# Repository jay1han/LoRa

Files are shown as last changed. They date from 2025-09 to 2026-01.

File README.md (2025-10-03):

# LoRa

This umbrella project contains several components utilizing LoRa for long-range, small-payload
communication for battery-driven applications.

## CellLoRa

This edge application collects atmospheric measurements (temperature, humidity) at hourly intervals
and sends a small data packet through LoRa. When not performing measurements, the module enters
a deep sleep state that consumes a few &mu;A of power. The module is powered by 3 AA batteries in series,
delivering between 3.5 and 5.0V, feeding a down-converter to 3.3V suitable for the electronics.
At each measurement time, the output voltage of the batteries is also measured,
so that a user can anticipate a low battery condition.

The CPU is a ESP32-C3 module, and atmospheric measurement is done with a AHT10.
Battery voltage is measured with a simple 10:1 resistor bridge connected to one of the internal
ADCs of the ESP32-C3. LoRa is provided by a Ra-02 module from AI-Thinker, which uses a SX1278
and is optimized for 433MHz. A relay and transistor is used to control power supply to it.

The system has been tested to run for several months on a set of 3 batteries.
The code has been optimized for reliability, doing 3 re-sends at maximum power, very low bandwidth
and high spread. Depending on the environment and the application, the reliability can be reduced
hence reducing power draw and extending battery life.

## LoRa2MQTT

This bridge application uses a ESP32-S2 with the same SX1280-based LoRa module.
It listens on the LoRa band for messages from edge applications, and takes appropriate action.
In the case of the CellLora, the incoming packet is parsed and the three measurements
(temperature, humidity, battery voltage) are bundled into a MQTT message.
Link to the MQTT broker goes through normal WiFi.

Additional edge devices can be added through the `Vector` array.
Some examples (`BalLoRa` and `Test`) have been provided for reference.

## Home Assistant

MQTT is used as the bridge for Home Assistant. A device named "CellLora" is self-registered
using the three configuration messages `temp.config`, `humi.config`, `batt.config`.
Use the `config.sh` script to run the self-registration, after the MQTT integration
has been enabled on Home Assistant.

After installing `mosquitto` and `mosquitto-client`,
create a password file:

```
mosquitto_passwd -c mosquitto.pwd <user>
```

then move the file `mosquitto.pwd` et `/etc/mosquitto`.

Add the following lines to `/etc/mosquitto/mosquitto.conf`:

```
per_listener_settings true
listener 1883
password_file /etc/mosquitto/mosquitto.pwd
```

then restart `mosquitto`.

Enable the MQTT integration of Home Assistant using the user/password defined above.

## About LoRa

LoRa, as its name implies, is optimized for long-range, low-bandwidth, broadcast communication
over unlicensed spectrum. Depending on geography, spectrum in the 433MHz, 915MHz, or 2.4GHz range
can be used. The lower frequencies typically allow better penetration while higher frequencies
allow higher bandwidth. In out *CellLoRa* application, the system has been tested to push data
from am enclosed cellar in the 2nd basement up to an appartement on the 5th floor of a concrete building.

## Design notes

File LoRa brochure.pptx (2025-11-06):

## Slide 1

Application LoRa pour mesure atmosphérique basse fréquence

Capteur atmosphérique

Relai MQTT

Fréquence de mesure : 1/heure
Distance à la base : plusieurs km (ou plusieurs étages)
Alimentation par 3 piles AA : endurance de plusieurs mois

Alimentation : 5V 200mA max.
Connexion Wi-Fi au broker MQTT
Intégration à Home Assistant

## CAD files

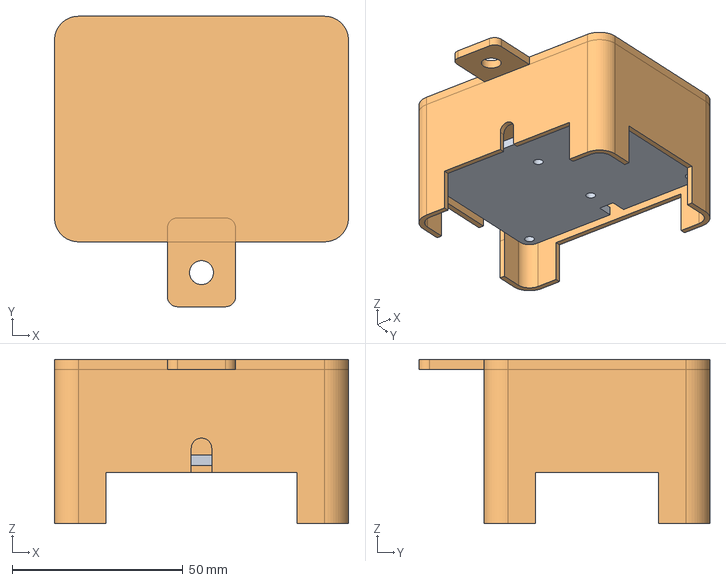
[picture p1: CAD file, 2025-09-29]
CellLora/CellLora.FCStd
86.0 x 85.0 x 48.0 mm
Base
Top

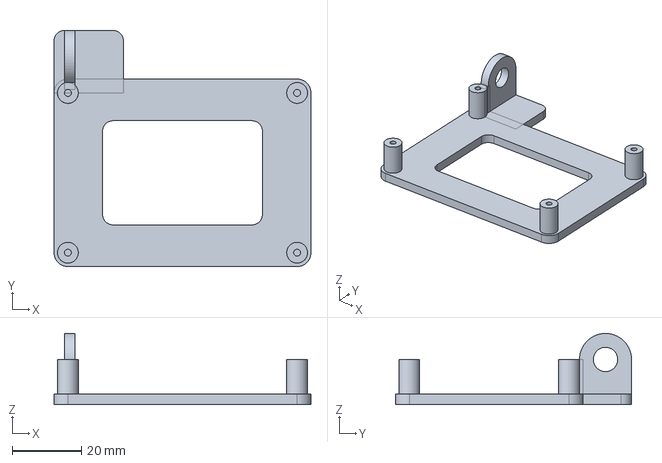
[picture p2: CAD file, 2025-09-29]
LoRa2MQTT/LoRa2MQTT.FCStd
74.0 x 68.0 x 20.5 mm

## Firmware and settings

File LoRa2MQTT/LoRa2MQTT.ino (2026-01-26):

#include <SPI.h>
#include <LoRa.h>
#include <WiFi.h>
#include <Wire.h>
#include <MQTT.h>
#include <Esp.h>

#define VERSION      "v200"

#define PIN_LED      15
#define PIN_BUTTON   0

#define LORA_RST     39
#define LORA_SCK     37
#define LORA_MISO    35
#define LORA_SS      33
#define LORA_MOSI    18
#define LORA_INT     16

#define I2C_SCL      3
#define I2C_SDA      5

#define SSID         "HORS SERVICE"
#define PASS         "babeface00"
WiFiClient wifiClient;

#define MQTT_SERVER  "192.168.0.86"
#define MQTT_TOPIC   "LoRa"
#define MQTT_CLIENT  "LoRa2MQTT"
#define MQTT_USER    "guest"
#define MQTT_PASSWD  "invitation"
MQTTClient mqttClient(1024);

// ----------------------------
// I2C for OLED display SSD1306

#define I2C_ADDR     0x3C

#define FONT_WIDTH    FONT_WIDTH_16
#define FONT_PITCH    (FONT_WIDTH + 1)
#define LCD_H_RES     128
#define LCD_V_RES     64
#define LCD_PAGES     (LCD_V_RES / 8)
#define LINE_WIDTH    (LCD_H_RES / FONT_PITCH / 2)
#include "fontdata.h"

const unsigned char ssd1306_init[] = {
    0xAE | 0x00,          // SET_DISP            off
    0xA0 | 0x01,          // SET_REG_REMAP       horizontal reverse start
    0xA8, LCD_V_RES - 1,  // SET_MUX_RATIO
    0xC0 | 0x08,          // SET_COM_OUT_DIR     horizontal reverse scan
    0xDA, 0x12,           // SET_COM_PIN_CFG     must be 0x02 if aspect ratio > 2:1, 0x12 otherwise
    0x20, 0x02,           // SET_MEM_ADDRESS     page mode
    0xD9, 0xF1,           // SET_PRECHARGE
    0xDB, 0x30,           // SET_VCOM_DESEL
    0x81, 0xFF,           // SET_CONTRAST
    0xA4,                 // SET_ENTIRE_ON
    0xA6 | 0x00,          // SET_NORM_INV (0x01 for inverse)
    0x8D, 0x14,           // SET_CHARGE_PUMP
    0xAE | 0x01,          // SET_DISP            on
};
unsigned char init_buffer[LCD_H_RES / 2 + 1];

void ssd1306_cmd(unsigned char cmd) {
    Wire.beginTransmission(I2C_ADDR);
    Wire.write(0x80);
    Wire.write(cmd);
    Wire.endTransmission();
}

void screenOn(bool on) {
    ssd1306_cmd(0x81);
    if (on) ssd1306_cmd(0xFF);
    else ssd1306_cmd(0x00);
}

void screenSaver(bool toggle) {
    static unsigned long lastOn = millis();
    static bool state = true;

    if (toggle) {
        if (!state) {
            screenOn(true);
            state = true;
            lastOn = millis() / 1000;
        } else {
            screenOn(false);
            state = false;
        }
    } else {
        if (state) {
            unsigned long now = millis() / 1000;
            if (now - lastOn > 60) {
                screenOn(false);
                state = false;
            }
        }
    }
}

void sendPagePos(int page, int pos, unsigned char *thisBuffer, int length) {
    ssd1306_cmd(0xB0 | page);
    ssd1306_cmd(0x00 | (pos & 0x0F));
    ssd1306_cmd(0x10 | (pos >> 4));
        
    Wire.beginTransmission(I2C_ADDR);
    Wire.write(0x40);
    Wire.write(thisBuffer, length);
    Wire.endTransmission();
}

void initDisplay() {
    memset(init_buffer, 0, sizeof(init_buffer));
    Wire.begin(I2C_SDA, I2C_SCL, 400000);
    Wire.beginTransmission(I2C_ADDR);
    if (Wire.endTransmission() == 0) {
        for (int i = 0; i < sizeof(ssd1306_init); i++) {
            ssd1306_cmd(ssd1306_init[i]);
        }

        for (int page = 0; page < LCD_PAGES; page ++) {
            sendPagePos(page, 0, init_buffer, sizeof(init_buffer));
            sendPagePos(page, LCD_H_RES / 2, init_buffer, sizeof(init_buffer));
        }
        Serial.println("I2C OLED initialized");
    } else {
        Serial.println("I2C OLED failed");
    }
}

byte nybble_low(byte original) {
    byte result = 0;
    for (int pos = 0; pos < 4; pos++) {
        if (original & (1 << pos)) result |= (3 << (pos * 2));
    }
    return result;
}

byte nybble_hi(byte original) {
    byte result = 0;
    for (int pos = 0; pos < 4; pos++) {
        if (original & (1 << (4 + pos))) result |= (3 << (pos * 2));
    }
    return result;
}

unsigned char lines[4][LCD_H_RES];

void writeBig(int line, char *text) {
    int target = 0;
    int i;

    for (i = 0; i < strlen(text) && i < LINE_WIDTH; i++) {
        int index = text[i];
        for (int col = 0; col < FONT_WIDTH_16; col++) {
            lines[0][target] = nybble_low(fontdata_top[index][col]);
            lines[1][target] = nybble_hi(fontdata_top[index][col]);
            lines[2][target] = nybble_low(fontdata_bot[index][col]);
            lines[3][target] = nybble_hi(fontdata_bot[index][col]);
            target++;
            lines[0][target] = nybble_low(fontdata_top[index][col]);
            lines[1][target] = nybble_hi(fontdata_top[index][col]);
            lines[2][target] = nybble_low(fontdata_bot[index][col]);
            lines[3][target] = nybble_hi(fontdata_bot[index][col]);
            target++;
        }
        lines[0][target] = lines[1][target] = lines[2][target] = lines[3][target] = 0x00;
        target++;
        lines[0][target] = lines[1][target] = lines[2][target] = lines[3][target] = 0x00;
        target++;
    }
    
    for (; target < LCD_H_RES; target++) {
        lines[0][target] = lines[1][target] = lines[2][target] = lines[3][target] = 0x00;
    }

    for (int sub = 0; sub < 4; sub++) {
        sendPagePos(line * 4 + sub, 0, lines[sub], target);
    }
}

// --------------------------------
// Global variables shared with ISR

#define MAX_PAYLOAD  16

#define ID_CELLAR   0xCE
#define ID_ERROR    0x55

struct {
    char message[16];
    char json[128];
    float battery;
    int rssi, snr;
} Rx;
byte payload[MAX_PAYLOAD];

#define HASS_TOPIC  "homeassistant/sensor/CellLora/state"
#define HASS_JSON   "{\"temperature\": %.1f, \"humidity\": %.0f, \"voltage\": %.1f}"

void sendMessage() {
    mqttClient.publish(MQTT_TOPIC, Rx.message);
    mqttClient.loop();
    if (!mqttClient.publish(HASS_TOPIC, Rx.json)) {
        Serial.println("Error publishing");
        sleep(1);
        ESP.restart();        
    }
    if (!mqttClient.loop()) {
        Serial.println("Loop error");
        sleep(1);
        ESP.restart();        
    }
}

char messageText[8];
char dataText[8];
void skipMessage(char *text) {
    while(LoRa.peek() >= 0) LoRa.read();
    if (text != NULL) {
        strcpy(messageText, text);
    }
}

bool isReceived = false;
void parseMessage(int packetSize) {
    int length = LoRa.available();
    if (length != packetSize) {
        skipMessage("PAYL");
        return;
    }
    
    for (int i = 0; i < length; i++) {
        payload[i] = LoRa.read();
    }
    
    float battery = (float)payload[0] / 10.0;
    float temperature = (float)payload[1] + (float)payload[2] / 10.0;
    float humidity = (float)payload[3];

    isReceived = false;
    do {
        if (battery > 5.0 || battery < 2.0) break;
        if (temperature > 50.0 || temperature <= 0.0) break;
        if (humidity >= 100.0 || humidity <= 10.0) break;
    
        sprintf(Rx.message, "%.1f %.0f", battery, temperature, humidity);
        sprintf(Rx.json, HASS_JSON, temperature, humidity, battery);
        
        Rx.battery = battery;
        Rx.rssi = -LoRa.packetRssi();
        Rx.snr  = LoRa.packetSnr() * 10.0;

        sprintf(dataText, "%3d%-4d", Rx.rssi, Rx.snr);
        skipMessage("");
        isReceived = true;
    } while(false);
    
    if (!isReceived) {
        skipMessage("DATA");
    }
}

/* Error codes
   1 = AHT10 Init
   2 = AHT10 Dead
   3 = AHT10 I2C
   4 = AHT10 I/O
*/
char ErrorText[5][2][8] = {
    {"ERROR", "CODING"},
    {"AHT10", "Init"},
    {"AHT10", "Dead"},
    {"AHT10", "I2C"},
    {"AHT10", "I/O"}
};

bool isError = false;
int errorCode = 0;
void parseError(int packetSize) {
    isError = true;
    errorCode = 0;
    
    int length = LoRa.available();
    if (length != packetSize) {
        skipMessage("PAYL");
        return;
    }
    
    for (int i = 0; i < length; i++) {
        payload[i] = LoRa.read();
    }

    errorCode = payload[0];
}

// CONTINUOUS, this is called from ISR!!!
void onReceive(int packetSize) {
    if (isReceived) {
        skipMessage("DUP");
        return;
    }
    
    if (packetSize == 0 || packetSize > MAX_PAYLOAD) {
        isError = true;
        errorCode = 0;
        return;
    }

    isError = false;
    byte senderCode = LoRa.read();
    if (senderCode == ID_CELLAR) parseMessage(packetSize - 1);
    else parseError(packetSize - 1);
}


// -----------------
// Setup code proper

void setup() {
    Serial.begin(115200);
    
    pinMode(PIN_LED, OUTPUT);
    digitalWrite(PIN_LED, LOW);
    pinMode(LORA_RST, OUTPUT);
    digitalWrite(LORA_RST, HIGH);
    delay(200);
    digitalWrite(LORA_RST, LOW);
    delay(200);
    digitalWrite(LORA_RST, HIGH);
    
    delay(1000);
    Serial.print("Starting ");
    Serial.println(VERSION);

    pinMode(PIN_BUTTON, INPUT_PULLUP);
    
    WiFi.begin(SSID, PASS);

    initDisplay();
    writeBig(0, "START");

    SPI.begin(LORA_SCK, LORA_MISO, LORA_MOSI, LORA_SS);
    pinMode(LORA_INT, INPUT_PULLUP);
    LoRa.setPins(LORA_SS, LORA_RST, LORA_INT);

    if (!LoRa.begin(433E6)) {
        Serial.println("LoRa begin fail");
        sleep(1);
        ESP.restart();
    } else {
        LoRa.setSpreadingFactor(12);
        LoRa.setCodingRate4(8);
        LoRa.enableCrc();
        Serial.println("LoRa initialized");
    }

    int wait = 0;
    while (WiFi.status() != WL_CONNECTED) {
        delay(500);
        wait ++;
        if (wait > 20) {
            Serial.println("WiFi failed");
            delay(1000);
            ESP.restart();
        }
    }
    
    char ip[30] = "";
    strcpy(ip, (char*)WiFi.localIP().toString().c_str());
    Serial.println(ip);

    mqttClient.begin(MQTT_SERVER, wifiClient);
    mqttClient.setKeepAlive(3600);
    if (!mqttClient.connect(MQTT_CLIENT, MQTT_USER, MQTT_PASSWD)) {
        Serial.println("Can't connect to MQTT broker");
        sleep(1);
        ESP.restart();
    }
    mqttClient.publish(MQTT_TOPIC, ip, true, 0);

    Serial.println("MQTT connected");

    Serial.println("Listening...");
    writeBig(0, "OK");
    screenSaver(false);
    
    LoRa.onReceive(onReceive);
    LoRa.receive();
}

bool messageSent = false;
void loop() {
    static int lastReceived = 0;
    static int lastUpdate = -1;
    static int button = 0;

    if (isError) {
        if (errorCode >= 1 && errorCode <= 4) {
            writeBig(0, ErrorText[errorCode][0]);
            writeBig(1, ErrorText[errorCode][1]);
            Serial.println(ErrorText[errorCode][0]);
            Serial.println(ErrorText[errorCode][1]);
        } else {
            char code[8];
            snprintf(code, 7, "%d", errorCode);
            writeBig(0, "ERROR");
            writeBig(1, code);
            Serial.printf("ERROR %d\n", errorCode);
        }

        isError = false;
        return;
    }

    if (isReceived) {
        sendMessage();
        lastReceived = millis() / 60000;
        writeBig(1, dataText);
        Serial.println(dataText);
        isReceived = false;
    }

    if (digitalRead(PIN_BUTTON) != button) {
        button = 1 - button;
        if (button) screenSaver(true);
    }
    
    int minutes = millis() / 60000 - lastReceived;
    if (minutes != lastUpdate || messageText[0] != 0) {
        char timeText[8];
        lastUpdate = minutes;
        
        sprintf(timeText, "%2d %s", minutes, messageText);
        writeBig(0, timeText);
        if (messageText[0] != 0) Serial.println(timeText);
        
        if (minutes > 60) {
            Serial.println("No data");
            sleep(1);
            ESP.restart();
        }
    }

    if (!WiFi.isConnected()) {
      Serial.println("WiFi disconnected");
      sleep(1);
      ESP.restart();
    }
    
    if (!mqttClient.connected()) {
      Serial.println("MQTT failure");
      sleep(1);
      ESP.restart();
    }

    if (lastReceived > 60 * 24 * 30) {
      Serial.println("Sanitary reboot");
      sleep(1);
      ESP.restart();
    }

    screenSaver(false);
    if (!mqttClient.loop()) {
        Serial.println("Loop error");
        sleep(1);
        ESP.restart();        
    }
}

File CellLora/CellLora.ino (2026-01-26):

#include "esp_sleep.h"
#include <SPI.h>
#include <LoRa.h>
#include <Wire.h>
#include <Esp.h>

char VERSION[20] = "CellLora v110";

#define UART_TX    21
#define UART_RX    2      // with pull-up for strapping
#define PIN_ADC    4
#define I2C_SDA    0
#define I2C_SCL    1
#define I2C_AHT10  0x38

#define LORA_POWER 3
#define LORA_MOSI  10
#define LORA_SS    20
#define LORA_MISO  5
#define LORA_SCK   6
#define LORA_RST   7
#define LORA_INT   -1

#define SLEEP_SECONDS_FULL  (30 * 60) // Every 30 minutes
#define SLEEP_SECONDS_RETRY 60
unsigned int sleepSeconds;
#define ID_CELLAR   0xCE
#define ID_ERROR    0x55

// Send LoRa packet
bool sendPacket1(byte id, byte *payload, int size) {
    if (LoRa.beginPacket() == 0) {
        Serial.println("LoRa can't start packet");
        return false;
    } else {
        LoRa.write(id);

        for (int i = 0; i < size; i++) {
            LoRa.write(payload[i]);
        }

        if (LoRa.endPacket() == 0) {
            Serial.println("can't send packet");
            return false;
        }
    }
    
    return true;
}

bool sendPacket(byte *payload, int size) {
    bool result = false;
    result = result || sendPacket1(ID_CELLAR, payload, size);
    sleep(1);
    result = result || sendPacket1(ID_CELLAR, payload, size);
    sleep(1);
    result = result || sendPacket1(ID_CELLAR, payload, size);
    return result;
}

#define ERR_AHT10_INIT   1
#define ERR_AHT10_DEAD   2
#define ERR_AHT10_I2C    3
#define ERR_AHT10_IO     4

void error(int code) {
    byte payload[4];
    payload[0] = code;
    sendPacket1(ID_ERROR, payload, 1);
}

// Everything happens in setup()

unsigned long processTime;
void setup() {
    processTime = millis();
    sleepSeconds = SLEEP_SECONDS_RETRY; // In case something goes wrong
    Serial.begin(115200, SERIAL_8N1, UART_RX, UART_TX);
    Serial.println(VERSION);

// Initialize LoRa module
    pinMode(LORA_POWER, OUTPUT);
    digitalWrite(LORA_POWER, HIGH);
    SPI.begin(LORA_SCK, LORA_MISO, LORA_MOSI, LORA_SS);
    LoRa.setPins(LORA_SS, LORA_RST);
    if (LoRa.begin(433E6) == 0) {
        Serial.println("LoRa begin fail");
        return;
    } else {
        LoRa.setSpreadingFactor(12);
        LoRa.setCodingRate4(8);
        LoRa.enableCrc();
        Serial.println("LoRa init OK");
    }

// Read battery voltage    
    pinMode(PIN_ADC, ANALOG);

    int mV = 0;
    for (int i = 0; i < 11; i++) {
        mV += analogReadMilliVolts(PIN_ADC);
        delay(10);
    }
    float voltage = mV / 1000.0;
    Serial.printf("Battery %.1fV\n", voltage);

// Initialize AHT10
    Serial.print("Initialize AHT10 ");
    Wire.begin(I2C_SDA, I2C_SCL, 400000);
    Wire.beginTransmission(I2C_AHT10);
    Wire.write(0xE1);
    Wire.write(0x08);
    Wire.write(0x00);
    if (Wire.endTransmission() == 0) {
        Serial.print("...");
        if (Wire.requestFrom(I2C_AHT10, 1) == 1) {
            byte status = Wire.read();
            Serial.printf("AHT10 Status=0x%02X ", status);
            if ((status & 0x68) == 0x08) {
                Serial.println("OK");
            } else {
                Serial.println("NG");
                error(ERR_AHT10_INIT);
                return;
            }
        } else {
            Serial.println("not responding");
            error(ERR_AHT10_DEAD);
            return; 
        }
    } else {
        Serial.println("not found");
        error(ERR_AHT10_I2C);
        return;
    }

// Read AHT10 data
    int length = 0;
    byte buffer[6];
    float temperature, humidity;
    
    Serial.print("AHT10 read data... ");
    unsigned long aht10Time = millis();
    Wire.beginTransmission(I2C_AHT10);
    Wire.write(0xAC);
    Wire.write(0x33);
    Wire.write(0x00);
    if (Wire.endTransmission() != 0) {
        Serial.println("send command failed");
        error(ERR_AHT10_IO);
        return;
    } else {
        delay(100);

        while (true) {
            Serial.print(".");
            length = Wire.requestFrom(I2C_AHT10, 6);
            if (length < 6) {
                delay(100);
            } else {
                length = Wire.readBytes(buffer, 6);
                if (length == 6 && (buffer[0] & 0x80) == 0) break;
                else delay(100);
            }
        }
        Serial.printf(" Done in %dms\n", millis() - aht10Time);

        unsigned int rawHum  = ((buffer[1] << 16) | (buffer[2] << 8) | buffer[3]) >> 4;
        unsigned int rawTemp = ((buffer[3] & 0x0F) << 16) | (buffer[4] << 8) | buffer[5];
        humidity    = (100.0 * (float)rawHum) / (1 << 20);
        temperature = ((200.0 * (float)rawTemp) / (1 << 20)) - 50.0;
        Serial.printf("Temp=%d=%.2f Hum=%d=%.2f\n",
                      rawTemp, temperature,
                      rawHum,  humidity);
    }

// Build LoRa packet
    byte payload[4];

    int battery = int(voltage * 10.0 + 0.5);
    payload[0] = battery;

    int temp_dec = int(temperature * 10.0 + 0.5);
    int temp_int = temp_dec / 10;
    temp_dec -= temp_int * 10;
    payload[1] = temp_int;
    payload[2] = temp_dec;

    int humi_int = int(humidity);
    payload[3] = humi_int;

// Send LoRa packet
    Serial.println("Send packet");
    if (!sendPacket(payload, 4)) return;

// All good, sleep for full period
    sleepSeconds = SLEEP_SECONDS_FULL;
}

// loop() does the cleanup and goes to sleep
void loop() {
    LoRa.sleep();
    digitalWrite(LORA_POWER, LOW);
    
    uint64_t sleepTime = (sleepSeconds * 1000000L) - (millis() - processTime + 1) * 1000L;
    Serial.printf("Processing time %d ms, sleep for %ld seconds\n",
                  millis() - processTime, sleepTime / 1000000);
    Serial.flush();

    esp_sleep_enable_timer_wakeup(sleepTime);
    esp_deep_sleep_start();
}

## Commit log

2023-10-27 Ready for assembly
2023-10-31 The box
    [CellLora-Center.stl, CellLora-PCB.stl, CellLora.FCStd]
2023-11-01 Including box
    [13 LoRa2MQTT-Base.stl, 14 LoRa2MQTT-Cover.stl, LoRa2MQTT.FCStd]
2023-11-05 Button to wake up
2024-01-30 Home Assistant
    [LoRa2MQTT.FCStd]
2024-02-05 smaller hole
    [CellLora.FCStd]
2024-02-12 Temperature decimal
2026-01-26 30 minutes and errors
    [CellLora.ino, LoRa2MQTT.ino]
